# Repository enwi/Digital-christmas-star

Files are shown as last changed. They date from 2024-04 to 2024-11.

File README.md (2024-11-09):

# Digital-christmas-star

## Videos
Video 1 (https://www.youtube.com/watch?v=jLeo_D0pDiA)
Video 2 (https://www.youtube.com/watch?v=EICvJTpRVDk)

Special thanks to [PCBWay](https://www.pcbway.com/) for sponsoring the video!

## Parameters that need to be changed before upload
* DATA_PIN -> The IO pin to which the LED's are connnected
* NUM_FINS -> The number of fins (for a regular star 4-5)
* NUM_LEDS_BETWEEN_TIPS -> The number of LED's between the tips (not including tips)
* animationTime -> The time in milliseconds how long each animation is shown

## Adding new animations
* Add a new animation function
* Add a new case to the switch case
* Call the function in the created case
* Increase maxMode by 1 (set it to the same number as the last number of the switch case)

# Support
If you want to support my work you can store on Amazon via this link: [Amazon Referral Link](https://www.amazon.de/?tag=enwi-21). This is an affiliate link. Through a purchase via this link, I will participate in the turnover. This has no effect on the price for you.

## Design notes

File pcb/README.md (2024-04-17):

# Schematic
To view the schematic just follow [this link](https://kicanvas.org/?github=https%3A%2F%2Fgithub.com%2Fenwi%2FDigital-christmas-star%2Ftree%2Fmaster%2Fpcb)

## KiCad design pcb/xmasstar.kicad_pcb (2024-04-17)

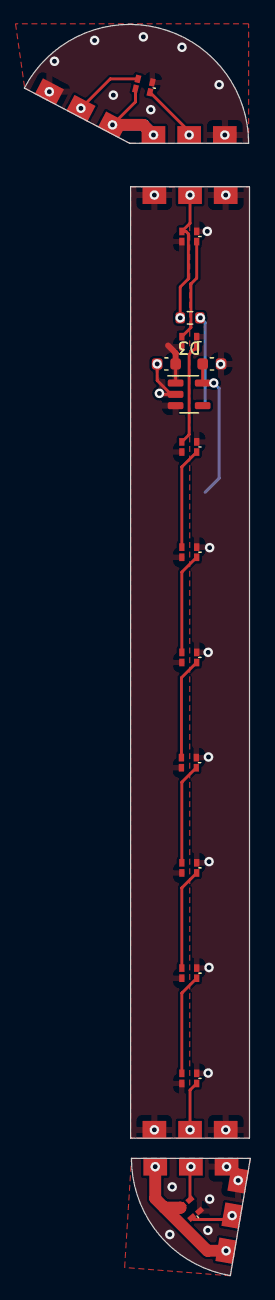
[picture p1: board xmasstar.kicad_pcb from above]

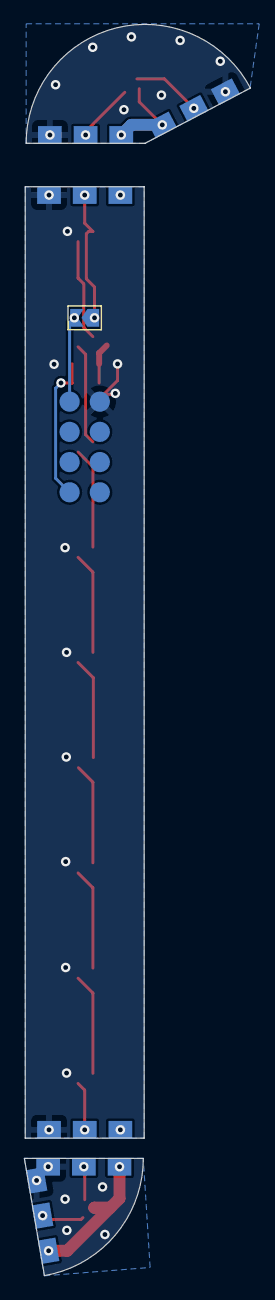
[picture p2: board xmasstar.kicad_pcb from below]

Board: 2 copper layers, 19.0 x 105.2 mm, 29 parts (8 on the bottom side), 18 nets.

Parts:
C1, C2: 1u; C_0603_1608Metric
D1, D2, D3, D4, D5, D6, D7, D8, D9, D10, D11: WS2812B; 1615RGBC
J1, J1#2, J2, J2#2, J4, J4#2, J5, J5#2, J6, J6#2, J7, J7#2: Conn_01x03; star_edge
J3: Conn_02x04_Odd_Even; 02x04_smd
JP1: SolderJumper_2_Open; SolderJumper-2_P1.3mm_Open_TrianglePad1.0x1.5mm
R1: 200; R_0603_1608Metric
U1: RT9167A-xxxB; TSOT-23-5

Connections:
+3V3: C2.1, J3.8, U1.5 (VOUT)
+5V: C1.1, D1.1 (VDD), D2.1 (VDD), D3.1 (VDD), D4.1 (VDD), D5.1 (VDD), D6.1 (VDD), D7.1 (VDD), D8.1 (VDD), D9.1 (VDD), D10.1 (VDD), D11.1 (VDD), J1.3, J1#2.3, J2.1, J2#2.1, J4.3, J4#2.3, J5.1, J5#2.1, J6.3, J6#2.3, J7.1, J7#2.1, U1.1 (VIN), U1.3 (EN)
DIN: D2.4 (DIN), J4.2, J4#2.2, JP1.1 (A), R1.2
GND: C1.2, C2.2, D1.3 (VSS), D2.3 (VSS), D3.3 (VSS), D4.3 (VSS), D5.3 (VSS), D6.3 (VSS), D7.3 (VSS), D8.3 (VSS), D9.3 (VSS), D10.3 (VSS), D11.3 (VSS), J1.1, J1#2.1, J2.3, J2#2.3, J3.1, J4.1, J4#2.1, J5.3, J5#2.3, J6.1, J6#2.1, J7.3, J7#2.3, U1.2 (GND)
unnamed: D1.4 (DIN), J1.2, J1#2.2
unnamed: D1.2 (DOUT), J2.2, J2#2.2
unnamed: D2.2 (DOUT), D3.4 (DIN)
unnamed: D3.2 (DOUT), D4.4 (DIN)
unnamed: D4.2 (DOUT), D5.4 (DIN)
unnamed: D5.2 (DOUT), D6.4 (DIN)
unnamed: D6.2 (DOUT), D7.4 (DIN)
unnamed: D7.2 (DOUT), D8.4 (DIN)
unnamed: D8.2 (DOUT), D9.4 (DIN)
unnamed: D9.2 (DOUT), D10.4 (DIN)
unnamed: D10.2 (DOUT), J5.2, J5#2.2
unnamed: D11.4 (DIN), J6.2, J6#2.2
unnamed: D11.2 (DOUT), J7.2, J7#2.2
TX: J3.2, JP1.2 (B), R1.1

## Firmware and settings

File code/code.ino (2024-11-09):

#define FASTLED_ALLOW_INTERRUPTS 0
#include <FastLED.h>

/**
 *Config
 **/
constexpr static const bool DEBUG = true; /// en-/disable debug output

constexpr static const uint8_t DATA_PIN = 0; /// The pin the leds are connected to
constexpr static const uint16_t NUM_FINS = 5; /// The number of fins the start has
constexpr static const uint16_t NUM_LEDS_BETWEEN_TIPS = 9; /// The number of leds between tips (without tip leds)
constexpr static const uint16_t LED_OFFSET = 0; /// Offset for first LED
//#define NO_TIP_AND_PIT_LEDS /// Uncomment this if you do not have LEDS in the tip or pit

// 60000 milliseconds = 1 minute
constexpr static const uint16_t animationTime = 60000; /// The time after which to change animation

constexpr static const uint8_t maxMode = 8; /// The mode count

/**
 * Internal variables
 **/
#if defined(NO_TIP_AND_PIT_LEDS)
constexpr static const uint16_t NUM_LEDS = (NUM_LEDS_BETWEEN_TIPS * NUM_FINS * 2);
constexpr static const uint16_t NUM_LEDS_IN_FIN = (2 * NUM_LEDS_BETWEEN_TIPS);
#else
constexpr static const uint16_t NUM_LEDS = (NUM_FINS * 2 + NUM_LEDS_BETWEEN_TIPS * NUM_FINS * 2);
constexpr static const uint16_t NUM_LEDS_IN_FIN = (2 * NUM_LEDS_BETWEEN_TIPS) + 1;
#endif
uint32_t lastAnimationTime = 0; /// The last time we changed the animation
uint32_t lastAnimationStep = 0; /// The last time we animated a step 1
uint32_t lastAnimationStep2 = 0; /// The last time we animated a step 2
uint8_t currentMode = 0; /// The current mode/animation we are in
uint8_t hue = 0; /// The color of the animation

CRGBArray<NUM_LEDS> leds; // Our leds

// forward declaration of function
bool animate(const uint32_t currentTime, const uint16_t animationStepTime);
bool animate2(const uint32_t currentTime, const uint16_t animationStepTime);
void lerp8(CPixelView<CRGB>& ledArray, const CHSV& color, const uint8_t fraction);
void lerp8(CRGB& color1, const CRGB& color2, const uint8_t fraction);
constexpr uint8_t convertPercent(const double percentage);
template <typename T>
void logParameter(const String& name, const T& value);
void mirrorFirstFin();
void copyFirstFinToAllFins();

bool circleRainbowAnimation(const uint32_t time);
bool rainbow(const uint32_t time);
bool randomTwinkle(const uint32_t time, const uint32_t color1, const uint32_t color2);
bool outsideRainbow(const uint32_t time);
bool circleAnimation(const uint32_t time, const CHSV& color);
bool staticColor(const CHSV& color);
bool staticTwinkle(const uint32_t time, const CHSV& color);
bool outsideWoosh(const uint32_t time);
bool simpleColorFade(const uint32_t time);

void setup()
{
    if (DEBUG)
    {
        Serial.begin(115200); // Enable serial output when debugging
    }
    // FastLED.addLeds<NEOPIXEL, DATA_PIN>(leds, NUM_LEDS);
    FastLED.addLeds<WS2812B, DATA_PIN>(leds, NUM_LEDS);
    // FastLED.setMaxPowerInVoltsAndMilliamps(5, 400); // Limit power to 2 Watts (5V * 0.4A)
    FastLED.setBrightness(128);
    leds.fill_solid(0x000000); // Clear all leds
    FastLED.show();
}

void loop()
{
    unsigned long currentMillis = millis();
    if (currentMillis - lastAnimationTime > animationTime) // Change the mode after the given animationTime
    {
        lastAnimationTime = currentMillis;
        ++currentMode;
        hue += 30;
        if (currentMode > maxMode) // Reset to first mode after last mode
        {
            currentMode = 0;
        }
    }

    logParameter("Time", currentMillis);

    bool show = false;
    switch (currentMode) // Run the animation associated with the mode
    {
    case 0:
        show = circleRainbowAnimation(currentMillis);
        break;
    case 1:
        show = rainbow(currentMillis);
        break;
    case 2:
        show = randomTwinkle(currentMillis, 0x00B315, 0xB3000C);
        break;
    case 3:
        show = outsideRainbow(currentMillis);
        break;
    case 4:
        show = circleAnimation(currentMillis, CHSV(hue, 255, 255));
        break;
    case 5:
        show = staticColor(CHSV(hue, 255, 255));
        break;
    case 6:
        show = outsideWoosh(currentMillis);
        break;
    case 7:
        show = simpleColorFade(currentMillis);
        break;
    case 8:
        show = staticTwinkle(currentMillis, CHSV(hue, 255, 255));
        break;
    default:
        currentMode = 0;
    }

    if (show)
    {
        LEDS.show(); // Show the animation
    }
}

bool rainbow(const uint32_t time)
{
    if (!animate(time, 30)) // Every 30 ms update the color
    {
        return false;
    }

    ++hue;
    for (uint8_t i = 0; i < NUM_LEDS; ++i)
    {
        uint16_t offset = (256 * i) / NUM_LEDS;
        leds[i].setHue((hue - offset) % 256);
    }
    return true;
}

bool randomTwinkle(const uint32_t time, const uint32_t color1, const uint32_t color2)
{
    if (!animate(time, 100)) // Every 100 ms fade by 20 and set random leds
    {
        return false;
    }

    leds.fadeToBlackBy(20);
    leds[random8(0, NUM_LEDS)] = color1;
    leds[random8(0, NUM_LEDS)] = color2;
    return true;
}

bool weirdAnimation(const uint32_t time)
{
    if (!animate(time, 30)) // Every 30 ms update the color
    {
        return false;
    }

    ++hue;

#if defined(NO_TIP_AND_PIT_LEDS)
    // Fill rainbow between first tips
    for (uint8_t i = 0; i < NUM_LEDS_BETWEEN_TIPS; ++i)
    {
        leds[i].setHue((hue - (255 / NUM_LEDS_BETWEEN_TIPS) * i) % 256);
    }
#else
    // Set tip and inner tip green
    leds[0] = leds[NUM_FINS + 1] = 0x00B315;

    // Fill rainbow between first tips
    for (uint8_t i = 0; i < NUM_LEDS_BETWEEN_TIPS; ++i)
    {
        leds[i + 1].setHue((hue - (255 / NUM_LEDS_BETWEEN_TIPS) * i) % 256);
    }
#endif
    mirrorFirstFin();
    copyFirstFinToAllFins();
    return true;
}

bool outsideWoosh(const uint32_t time)
{
#if defined(NO_TIP_AND_PIT_LEDS)
    constexpr static const uint16_t LED_COUNT = NUM_LEDS_BETWEEN_TIPS;
#else
    constexpr static const uint16_t LED_COUNT = NUM_LEDS_BETWEEN_TIPS + 2;
#endif
    static uint8_t animationStep = 0;

    if (!animate(time, 100)) // Every 100 ms update the color
    {
        return false;
    }

    leds.fadeToBlackBy(convertPercent(300.0 / LED_COUNT));

    if (animationStep < LED_COUNT) // Don't animate all the time to have time to fade to black
    {
        leds[(animationStep + LED_OFFSET) % NUM_LEDS] = CHSV(hue, 255, 255);
        mirrorFirstFin();
        copyFirstFinToAllFins();
        ++hue;
    }

    ++animationStep;
    if (animationStep >= 2 * LED_COUNT)
    {
        animationStep = 0;
    }
    return true;
}

bool outsideRainbow(const uint32_t time)
{
#if defined(NO_TIP_AND_PIT_LEDS)
    constexpr static const uint16_t LED_COUNT = NUM_LEDS_BETWEEN_TIPS;
#else
    constexpr static const uint16_t LED_COUNT = NUM_LEDS_BETWEEN_TIPS + 2;
#endif

    if (!animate(time, 30)) // Every 30 ms update the color
    {
        return false;
    }

    ++hue;
    // Fill rainbow between first tips
    for (uint8_t i = 0; i < LED_COUNT; ++i)
    {
        leds[(i+LED_OFFSET) % NUM_LEDS].setHue((hue - (255 / (NUM_LEDS_IN_FIN)) * i) % 256);
    }

    mirrorFirstFin();
    copyFirstFinToAllFins();
    return true;
}

bool simpleColorFade(const uint32_t time)
{
    if (!animate(time, 30)) // Every 30 ms update the color
    {
        return false;
    }

    ++hue;
    staticColor(CHSV(hue, 255, 255));
    return true;
}

bool staticColor(const CHSV& color)
{
    leds.fill_solid(color);
    return true;
}

bool staticTwinkle(const uint32_t time, const CHSV& color)
{
    bool update = false;
    if (animate2(time, 50)) // Every 50 ms fade to black by 12.5 %
    {
        lerp8(leds, color, convertPercent(12.5)); // 12.5%
        update = true;
    }
    if (animate(time, 150))
    {
        leds[random8(0, NUM_LEDS)] = CRGB::White;
        update = true;
    }
    return update;
}

uint8_t finIndex = 0;
uint8_t animationStep = 0;

bool circleAnimation(const uint32_t time, const CHSV& color)
{
    if (!animate(time, 100)) // Every 100 ms update the color
    {
        return false;
    }

#if defined(NO_TIP_AND_PIT_LEDS)
    // TODO implement
#else
    const uint16_t ledInFinIndex = animationStep % ((2 * NUM_LEDS_BETWEEN_TIPS) + 3);
    // 5 fins -> 0 -> 2 -> 4 -> 1 -> 3 -> 0 -> 2 -> 4 -> 1 -> 3 -> 0
    if (ledInFinIndex == 0)
    {
        finIndex = (finIndex + NUM_FINS / 2) % NUM_FINS;
    }
    const uint16_t ledIndex = ((ledInFinIndex + finIndex * ((2 * NUM_LEDS_BETWEEN_TIPS) + 2)) + LED_OFFSET ) % NUM_LEDS;

    leds.fadeToBlackBy(convertPercent(200.0 / (NUM_LEDS_BETWEEN_TIPS + 2)));
    leds[ledIndex] = color;

    ++animationStep;
    if (animationStep >= ((2 * NUM_LEDS_BETWEEN_TIPS) + 3) * NUM_FINS)
    {
        animationStep = 0;
    }
#endif
    return true;
}

bool circleRainbowAnimation(const uint32_t time)
{
    if (!animate(time, 100)) // Every 100 ms update the color
    {
        return false;
    }

#if defined(NO_TIP_AND_PIT_LEDS)
    // TODO implement
#else
    const uint16_t ledInFinIndex = animationStep % ((2 * NUM_LEDS_BETWEEN_TIPS) + 3);
    // 5 fins -> 0 -> 2 -> 4 -> 1 -> 3 -> 0 -> 2 -> 4 -> 1 -> 3 -> 0
    if (ledInFinIndex == 0)
    {
        finIndex = (finIndex + NUM_FINS / 2) % NUM_FINS;
    }
    const uint16_t ledIndex = ((ledInFinIndex + finIndex * ((2 * NUM_LEDS_BETWEEN_TIPS) + 2)) + LED_OFFSET) % NUM_LEDS;

    leds.fadeToBlackBy(convertPercent(200.0 / (NUM_LEDS_BETWEEN_TIPS + 2)));
    leds[ledIndex] = CHSV(hue, 255, 255);
    ++hue;

    ++animationStep;
    if (animationStep >= ((2 * NUM_LEDS_BETWEEN_TIPS) + 3) * NUM_FINS)
    {
        animationStep = 0;
    }
#endif
    return true;
}

// Converts a given percentage to the FastLED percentage
constexpr uint8_t convertPercent(const double percentage)
{
    return percentage * 2.56;
}

// Mirrors the first half of the first fin to the second half
void mirrorFirstFin()
{
#if defined(NO_TIP_AND_PIT_LEDS)
    leds(NUM_LEDS_IN_FIN, NUM_LEDS_BETWEEN_TIPS) = leds(0, NUM_LEDS_BETWEEN_TIPS);
#else
    leds(NUM_LEDS_IN_FIN + LED_OFFSET, NUM_LEDS_BETWEEN_TIPS + 2 + LED_OFFSET) = leds(1 + LED_OFFSET, NUM_LEDS_BETWEEN_TIPS + 1 + LED_OFFSET);
#endif
}

// Copies the first fin to all other fins
void copyFirstFinToAllFins()
{
    if (LED_OFFSET > 0)
    {
      leds(0, LED_OFFSET - 1) = leds(NUM_LEDS_IN_FIN+1, NUM_LEDS_IN_FIN + LED_OFFSET);
    }

    for (uint16_t fin = 1; fin < (NUM_FINS-1); ++fin)
    {
#if defined(NO_TIP_AND_PIT_LEDS)
        const int finStart = (2 * fin * NUM_LEDS_BETWEEN_TIPS);
        leds(finStart, finStart + NUM_LEDS_IN_FIN) = leds(0, NUM_LEDS_IN_FIN);
#else
        const int finStart = (2 * fin * NUM_LEDS_BETWEEN_TIPS) + (fin * 2);
        leds(finStart+LED_OFFSET, finStart + NUM_LEDS_IN_FIN+LED_OFFSET) = leds(LED_OFFSET, NUM_LEDS_IN_FIN+LED_OFFSET);
#endif
    }

    uint16_t fin = NUM_FINS - 1;
    const int finStart = (2 * fin * NUM_LEDS_BETWEEN_TIPS) + (fin * 2);
    leds(finStart+LED_OFFSET, NUM_LEDS-1) = leds(finStart+LED_OFFSET - (NUM_LEDS_IN_FIN + 1), NUM_LEDS-1 - (NUM_LEDS_IN_FIN + 1));
}

// Helper function that returns true after the given animationStepTime has passed
bool animate(const uint32_t currentTime, const uint16_t animationStepTime)
{
    if (currentTime - lastAnimationStep > animationStepTime)
    {
        lastAnimationStep = currentTime;
        return true;
    }
    return false;
}

// second Helper function does the same as above but on a second timer
bool animate2(const uint32_t currentTime, const uint16_t animationStepTime)
{
    if (currentTime - lastAnimationStep2 > animationStepTime)
    {
        lastAnimationStep2 = currentTime;
        return true;
    }
    return false;
}

// Do a linear interpolation between the current color of eacg led in ledArray and the given color with the
// given fraction
void lerp8(CPixelView<CRGB>& ledArray, const CHSV& color, const uint8_t fraction)
{
    const CRGB rgbColor = CRGB(color);
    for (int i = 0; i < ledArray.size(); ++i)
    {
        lerp8(ledArray[i], rgbColor, fraction);
    }
}

// Do a linear interpolation between the two given colors and store the result in the first color object
void lerp8(CRGB& color1, const CRGB& color2, const uint8_t fraction)
{
    color1.r = lerp8by8(color1.r, color2.r, fraction);
    color1.g = lerp8by8(color1.g, color2.g, fraction);
    color1.b = lerp8by8(color1.b, color2.b, fraction);
}

// Log the given parameter when logging is enabled
// Ecpected output: "<name>: <value>"
template <typename T>
void logParameter(const String& name, const T& value)
{
    if (DEBUG)
    {
        Serial.print(name);
        Serial.print(": ");
        Serial.println(value);
    }
}

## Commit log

2020-11-29 Add option to have a star without tip and pit LEDs
2024-04-17 Add gitignore fix code for new star
    [code.ino]
2024-04-17 Add pcb
    [xmasstar.kicad_pcb, xmasstar.kicad_sch]
2024-04-17 Move pcb files into pcb folder
    [xmasstar.kicad_pcb, xmasstar.kicad_sch]
2024-04-17 Move custom footprints into custom xmasstar library
    [xmasstar.kicad_sch]
2024-04-17 Create schematic README.md
2024-10-30 Add LED_OFFSET and refactor code
2024-10-30 Update code.ino
    Removed bugs in LED_OFFSET aplication
    [code.ino]
2024-10-30 Update code.ino
    Remove different color step between last and first led
